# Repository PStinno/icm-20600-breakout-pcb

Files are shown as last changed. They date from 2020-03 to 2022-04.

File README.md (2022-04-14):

# icm-20600-breakout-pcb
Breakout board for the ICM 20600 3-axis Accelerometer and Gyroscope.



This board allows for use of the ICM 20600 3-axis Accelerometer + 3-axis Gyroscope, from TDK InvenSense, with both 3.3 and 5V microcontroller development boards. The sensor is powered by an onboard, low-dropout 1.8V regulator and level shifting circuitry is included for the SDA and SCL lines. As well as a 0.1 inch header for use on a bread-board, two JST-SH connectors are provided which are compatible with the Sparkfun Qwiic and Adafruit StemmaQT standards. These connectors allow for chaining of the board with other compatible boards.

Also included in the repository is a basic example for reading the sensor and configuring its measurement ranges from an Arduino Uno or similar microcontroller board. This prints readings to the USB serial port and a processing sketch is included that visualises data from two of the accelerometer axis (see above image).

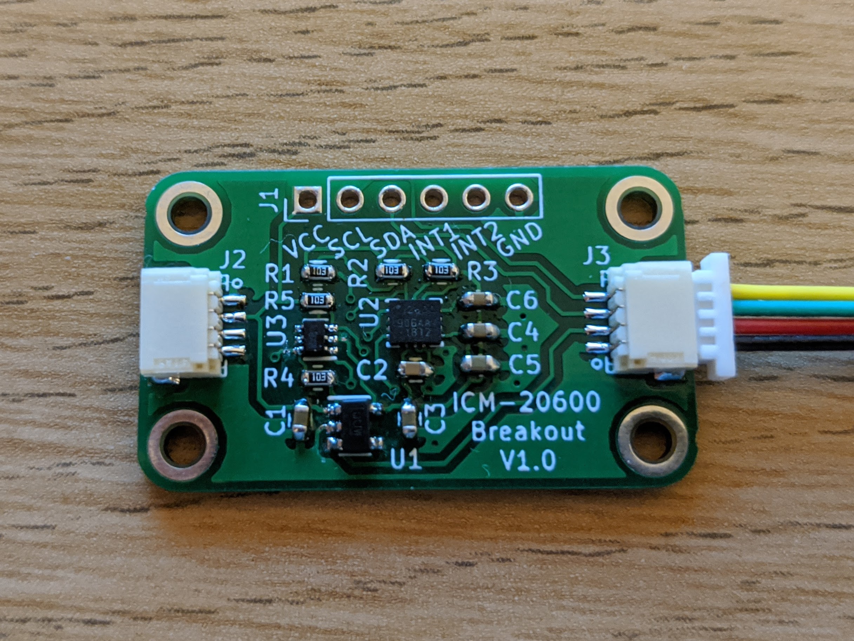
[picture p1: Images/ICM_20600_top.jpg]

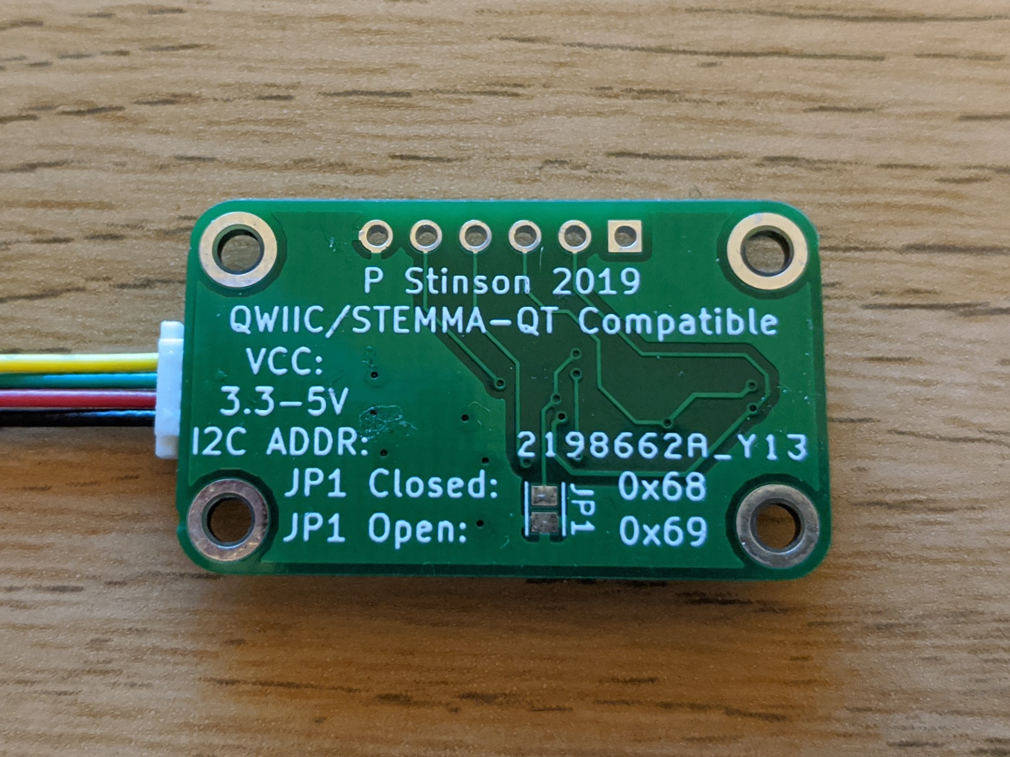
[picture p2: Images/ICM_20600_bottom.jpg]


[][cc-by-sa]

[cc-by-sa]: http://creativecommons.org/licenses/by-sa/4.0/
[cc-by-sa-image]: https://licensebuttons.net/l/by-sa/4.0/88x31.png
[cc-by-sa-shield]: https://img.shields.io/badge/License-CC%20BY--SA%204.0-lightgrey.svg

This work is licensed under a [Creative Commons Attribution-ShareAlike 4.0 International License][cc-by-sa].

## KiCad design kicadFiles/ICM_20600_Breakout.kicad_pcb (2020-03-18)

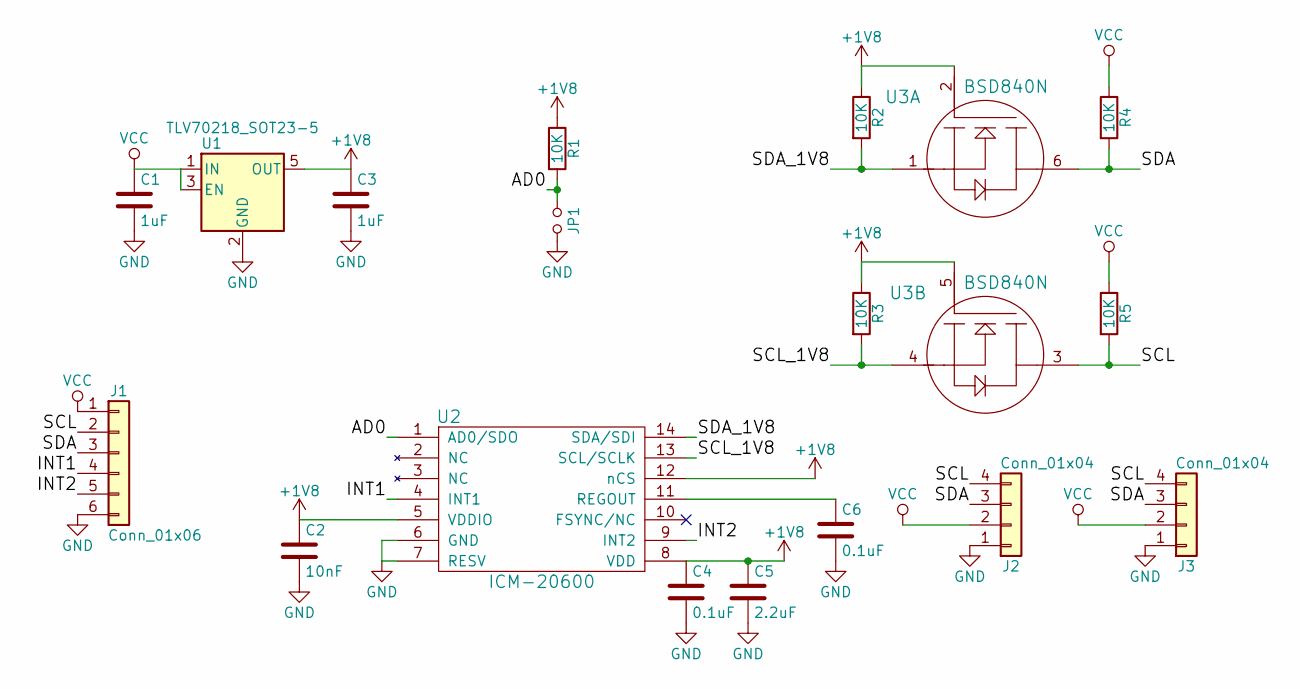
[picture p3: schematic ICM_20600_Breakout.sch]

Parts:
C1, C3: 1uF; C_0603
C2: 10nF; C_0603
C4, C6: 0.1uF; C_0603
C5: 2.2uF; C_0603
J1: Conn_01x06; Pin_Header_Straight_1x06_Pitch2.54mm
J2, J3: Conn_01x04; JST_SH_SM04B-SRSS-TB_04x1.00mm_Angled
JP1: Jumper_NO_Small; GS2
R1, R2, R3, R4, R5: 10K; R_0603
U1: TLV70218_SOT23-5; SOT-23-5
U2: ICM-20600; Bosch_LGA-14_3x2.5mm_Pitch0.5mm
U3: BSD840N; SOT-363_SC-70-6

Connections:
+1V8: C2.1, C3.1, C4.1, C5.1, R1.1, R2.1, R3.1, U1.5 (OUT), U2.5 (VDDIO), U2.8 (VDD), U2.12 (nCS), U3.2, U3.5
/AD0: JP1.1, R1.2, U2.1 (AD0/SDO)
/INT1: J1.4, U2.4 (INT1)
/INT2: J1.5, U2.9 (INT2)
/SCL: J1.2, J2.4, J3.4, R5.2, U3.3
/SCL_1V8: R3.2, U2.13 (SCL/SCLK), U3.4
/SDA: J1.3, J2.3, J3.3, R4.2, U3.6
/SDA_1V8: R2.2, U2.14 (SDA/SDI), U3.1
GND: C1.2, C2.2, C3.2, C4.2, C5.2, C6.2, J1.6, J2.1, J3.1, JP1.2, U1.2 (GND), U2.6 (GND), U2.7 (RESV)
unnamed: C6.1, U2.11 (REGOUT)
VCC: C1.1, J1.1, J2.2, J3.2, R4.1, R5.1, U1.1 (IN), U1.3 (EN)

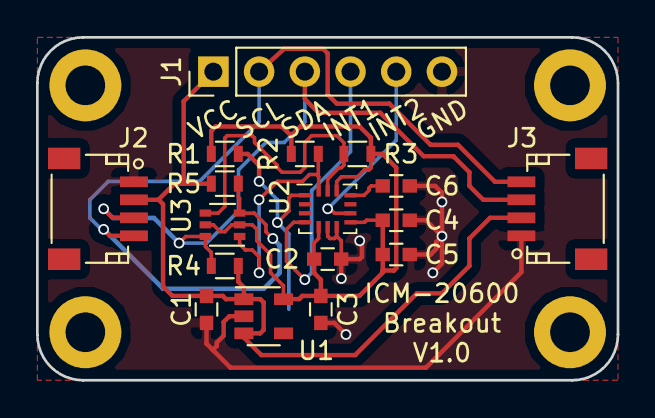
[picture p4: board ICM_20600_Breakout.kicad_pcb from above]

Board: 2 copper layers, 32.3 x 19.1 mm, 18 parts (1 on the bottom side), 11 nets.

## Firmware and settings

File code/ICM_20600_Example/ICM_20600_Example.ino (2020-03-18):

#include "ICM_20600.h"

ICM_20600 icm;

#define debugMode false

void setup() {
  Serial.begin(9600);
  
  if (debugMode) Serial.println("Initialising ICM 20600...");
  if (icm.init()) {
    if (debugMode) Serial.println("Success");
  } else {
    if (debugMode) Serial.println("Failure");
    while(1) {
      delay(100);
    }
  }

  /* Edit/Print Accelerometer Range */
  //icm.setAccelRange(ICM_20600_ACCEL_RANGE_8_G);

  if (debugMode) {
    icm_20600_accel_range_t range = icm.readAccelRange();
    if (range == ICM_20600_ACCEL_RANGE_2_G)
      Serial.println("2G");
    if (range == ICM_20600_ACCEL_RANGE_4_G)
      Serial.println("4G");
    if (range == ICM_20600_ACCEL_RANGE_8_G)
      Serial.println("8G");
    if (range == ICM_20600_ACCEL_RANGE_16_G)
      Serial.println("16G");
  }

  /* Edit/Print Gyroscope Range */
  //icm.setGyroRange(ICM_20600_GYRO_RANGE_1000_DPS);

  if (debugMode) {
    icm_20600_gyro_range_t rangeG = icm.readGyroRange();
    if (rangeG == ICM_20600_GYRO_RANGE_250_DPS)
      Serial.println("250DPS");
    if (rangeG == ICM_20600_GYRO_RANGE_500_DPS)
      Serial.println("500DPS");
    if (rangeG == ICM_20600_GYRO_RANGE_1000_DPS)
      Serial.println("1000DPS");
    if (rangeG == ICM_20600_GYRO_RANGE_2000_DPS)
      Serial.println("2000DPS");
  }
}

void loop() {
  // Get latest readings from ICM 20600
  icm.readVals();

  if (debugMode) {
    /* Slow print mode with formatting */
    // Print accelerometer readings
    Serial.println("");
    Serial.print("Accelerometer: ");
    Serial.print("x: ");
    Serial.print(icm.accelX());
    Serial.print(", y: ");
    Serial.print(icm.accelY());
    Serial.print(", z: ");
    Serial.print(icm.accelZ());
    Serial.println("   G");
  
    // Print gyroscope readings
    Serial.print("Gyroscope:     ");
    Serial.print("x: ");
    Serial.print(icm.gyroX());
    Serial.print(", y: ");
    Serial.print(icm.gyroY());
    Serial.print(", z: ");
    Serial.print(icm.gyroZ());
    Serial.println("   DPS");
    delay(500);
  } else {
    /* Fast print mode with comma-seperation only */
    Serial.print(icm.accelX());
    Serial.print(",");
    Serial.print(icm.accelY());
    Serial.print(",");
    Serial.print(icm.accelZ());
    Serial.print(",");
    Serial.print(icm.gyroX());
    Serial.print(",");
    Serial.print(icm.gyroY());
    Serial.print(",");
    Serial.println(icm.gyroZ());
    delay(50);
  }
}

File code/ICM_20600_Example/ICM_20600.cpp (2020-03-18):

#include "Arduino.h"
#include <Wire.h>

#include "ICM_20600.h"

ICM_20600::ICM_20600(void) {}

bool ICM_20600::init(uint8_t addr) {
  // Assign instance address
  i2c_addr = addr;
  // Start i2c
  Wire.begin();
  // Write configuration register
  writeReg(i2c_addr, ICM_20600_CONFIG, 0x00);
  // Write power management register
  writeReg(i2c_addr, ICM_20600_PWR_MGMT_1, 0x01);
  // Check ID
  uint8_t id = readReg(i2c_addr, ICM_20600_WHO_AM_I);
  if (id != ICM_20600_DEVICE_ID) {
    return false;
  }

  return true;
}

bool ICM_20600::init(void) {
  return init(ICM_20600_DEFAULT_ADDR);
}

/* ---Read Functions--- */
void ICM_20600::readTemp() {
  uint8_t tempH = readReg(i2c_addr, ICM_20600_TEMP_OUT_H);
  uint8_t tempL = readReg(i2c_addr, ICM_20600_TEMP_OUT_L);
  uint16_t temp = (tempH << 8) | tempL;
  tmp = (temp/326.8F)+25;
}

void ICM_20600::readAccel() {
  uint8_t xH = readReg(i2c_addr, ICM_20600_ACCEL_XOUT_H);
  uint8_t xL = readReg(i2c_addr, ICM_20600_ACCEL_XOUT_L);
  int x = (xH << 8) | xL;
  uint8_t yH = readReg(i2c_addr, ICM_20600_ACCEL_YOUT_H);
  uint8_t yL = readReg(i2c_addr, ICM_20600_ACCEL_YOUT_L);
  int y = (yH << 8) | yL;
  uint8_t zH = readReg(i2c_addr, ICM_20600_ACCEL_ZOUT_H);
  uint8_t zL = readReg(i2c_addr, ICM_20600_ACCEL_ZOUT_L);
  int z = (zH << 8) | zL;

  float scale = scaleAccel();
  accX = x/scale;
  accY = y/scale;
  accZ = z/scale;
}

void ICM_20600::readGyro() {
  uint8_t xH = readReg(i2c_addr, ICM_20600_GYRO_XOUT_H);
  uint8_t xL = readReg(i2c_addr, ICM_20600_GYRO_XOUT_L);
  int x = (xH << 8) | xL;
  uint8_t yH = readReg(i2c_addr, ICM_20600_GYRO_YOUT_H);
  uint8_t yL = readReg(i2c_addr, ICM_20600_GYRO_YOUT_L);
  int y = (yH << 8) | yL;
  uint8_t zH = readReg(i2c_addr, ICM_20600_GYRO_ZOUT_H);
  uint8_t zL = readReg(i2c_addr, ICM_20600_GYRO_ZOUT_L);
  int z = (zH << 8) | zL;

  float scale = scaleGyro();
  gyrX = x/scale;
  gyrY = y/scale;
  gyrZ = z/scale;
}

void ICM_20600::readVals() {
  readTemp();
  readAccel();
  readGyro();
}

icm_20600_accel_range_t ICM_20600::readAccelRange() {
  uint8_t regVal = readReg(i2c_addr, ICM_20600_ACCEL_CONFIG);
  return (icm_20600_accel_range_t) ((regVal & 0x18) >> 3);
}

icm_20600_gyro_range_t ICM_20600::readGyroRange() {
  uint8_t regVal = readReg(i2c_addr, ICM_20600_GYRO_CONFIG);
  return (icm_20600_gyro_range_t) ((regVal & 0x18) >> 3);
}

/* ---Set Functions--- */
void ICM_20600::setAccelRange(icm_20600_accel_range_t range) {
  uint8_t regVal = (uint8_t) (range << 3);
  writeReg(i2c_addr, ICM_20600_ACCEL_CONFIG, regVal);
}

void ICM_20600::setGyroRange(icm_20600_gyro_range_t range) {
  uint8_t regVal = (readReg(i2c_addr, ICM_20600_GYRO_CONFIG) & 0xE7) | ((uint8_t) (range << 3));
  writeReg(i2c_addr, ICM_20600_GYRO_CONFIG, regVal);
}

/* ---Get Functions--- */
float ICM_20600::temp() {
  return tmp;
}

float ICM_20600::accelX() {
  return accX;
}

float ICM_20600::accelY() {
  return accY;
}

float ICM_20600::accelZ() {
  return accZ;
}

float ICM_20600::gyroX() {
  return gyrX;
}

float ICM_20600::gyroY() {
  return gyrY;
}

float ICM_20600::gyroZ() {
  return gyrZ;
}

/* ---Private Functions--- */
void ICM_20600::writeReg(uint8_t addr, uint8_t reg, uint8_t data) {
  Wire.beginTransmission(addr);
  Wire.write(reg);
  Wire.write(data);
  Wire.endTransmission();
}

uint8_t ICM_20600::readReg(uint8_t addr, uint8_t reg) {
  uint8_t retVal = 0xFF;
  Wire.beginTransmission(addr);
  Wire.write(reg);
  Wire.endTransmission(false);
  Wire.requestFrom(addr, (uint8_t) 1);
  if (Wire.available() >= 1) {
   retVal = Wire.read();
  }
  return retVal;
}

float ICM_20600::scaleAccel() {
  icm_20600_accel_range_t range = readAccelRange();
  if (range == ICM_20600_ACCEL_RANGE_2_G)
    return 16384.0F;
  if (range == ICM_20600_ACCEL_RANGE_4_G)
    return 8192.0F;
  if (range == ICM_20600_ACCEL_RANGE_8_G)
    return 4096.0F;
  if (range == ICM_20600_ACCEL_RANGE_16_G)
    return 2048.0F;

   return 1.0;
}

float ICM_20600::scaleGyro() {
  icm_20600_gyro_range_t rangeG = readGyroRange();
  if (rangeG == ICM_20600_GYRO_RANGE_250_DPS)
    return 131.0F;
  if (rangeG == ICM_20600_GYRO_RANGE_500_DPS)
    return 65.5F;
  if (rangeG == ICM_20600_GYRO_RANGE_1000_DPS)
    return 32.8F;
  if (rangeG == ICM_20600_GYRO_RANGE_2000_DPS)
    return 16.4F;

   return 1.0;
}

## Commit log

2020-03-18 Added Kicad design files
    [ICM_20600_Breakout-B.Cu.gbl, ICM_20600_Breakout-B.Mask.gbs, ICM_20600_Breakout-B.SilkS.gbo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]
2020-03-18 Added Arduino and Processing code for usage example

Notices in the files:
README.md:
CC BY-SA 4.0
